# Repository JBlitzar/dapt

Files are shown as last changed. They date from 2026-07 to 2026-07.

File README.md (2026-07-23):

# dapt

## [Please read] About cost.

So looking at the bom, you can see that it's super expensive, like $50. You might be thinking, "what's going on there? I thought this project was explicitly focused on being low-cost!"

There are a few points I'd like to preempt.

1. I'm not going to spend $50 building this, and if I do so it'll be fine because I can pay out of pocket. That's the BOM for the souped-up set of ALL the adapters in large quantities. I'm going to pick and choose which ones to do, and do it in small quantities. I'm going to end up paying like $15 personally. 
2. There's not really a way to BOM-optimize. Contention genuinely is really high, because LCSC doesn't specialize in THT hobby-solderable components. USB-C SMD genuinely cannot be hand-soldered without a hot plate. If you're trying to make 100 of these, please just buy PCBA and get dirt-cheap SMD components. Right now THT pricing is hit-or-miss. Some are dirt cheap, others are not. 
3. I *could* swap everything out for SMD and order PCBA myself, but at that point it's genuinely a different project. This is what there is. 

## Images

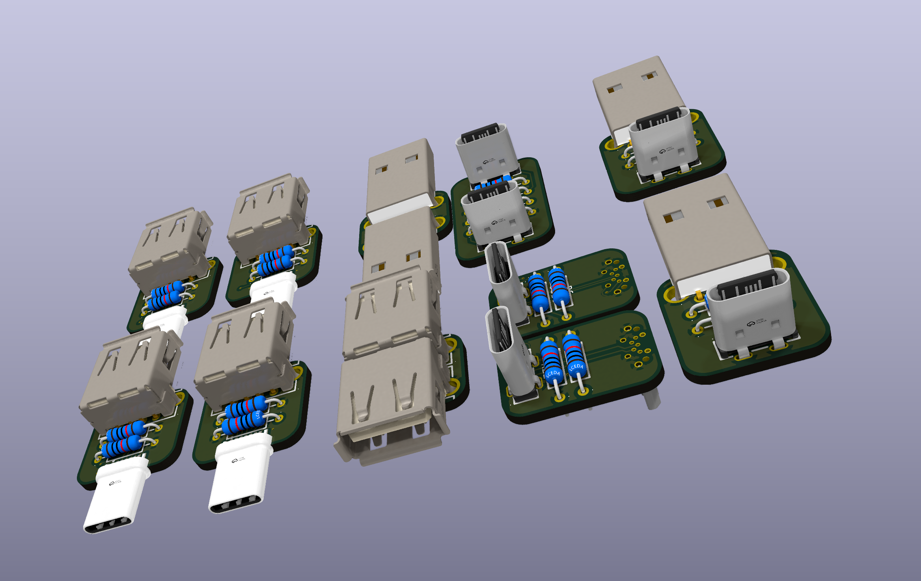
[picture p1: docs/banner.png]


There are no other enclosures, so this is the 3D model too. A STEP export is at `dapt.step`

## What is this project?

dapt is a family of USB adapters. 

There are some opinionated choices that were made:

- Fully passive and chipless. This means that it's just the bare USB protocol: GND, VCC, D+, D-. This also means that you lose out on PD and USB3.0. It's out of scope, but it's what makes this so universal. The only component other than the connectors are some 5.1k resistors that are required for all USB-C to work. 
- tht (for now). This is so that it's hand-solderable.
- just USB. It doesn't try to do too much.

I made dapt because I wanted some dead-simple USB adapters, and I thought it'd be a fun project.

Current adapters:
- A female to A female
- A female to C male
- A male to A male
- A male to C female
- C female to C female
- C female to micro male

## Schematics

| Variant | Schematic |
|---|---|
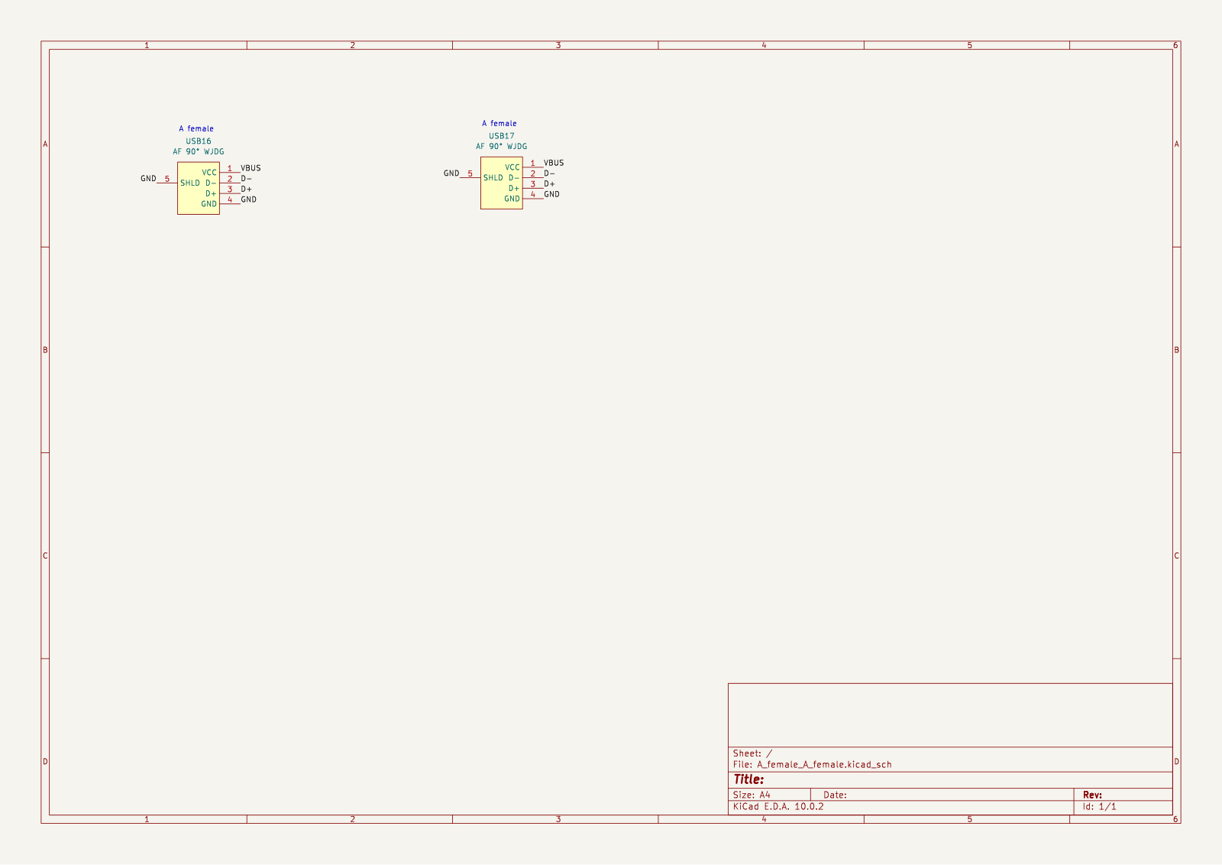
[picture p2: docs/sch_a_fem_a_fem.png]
A female to A female schematic
| A female to A female |  |
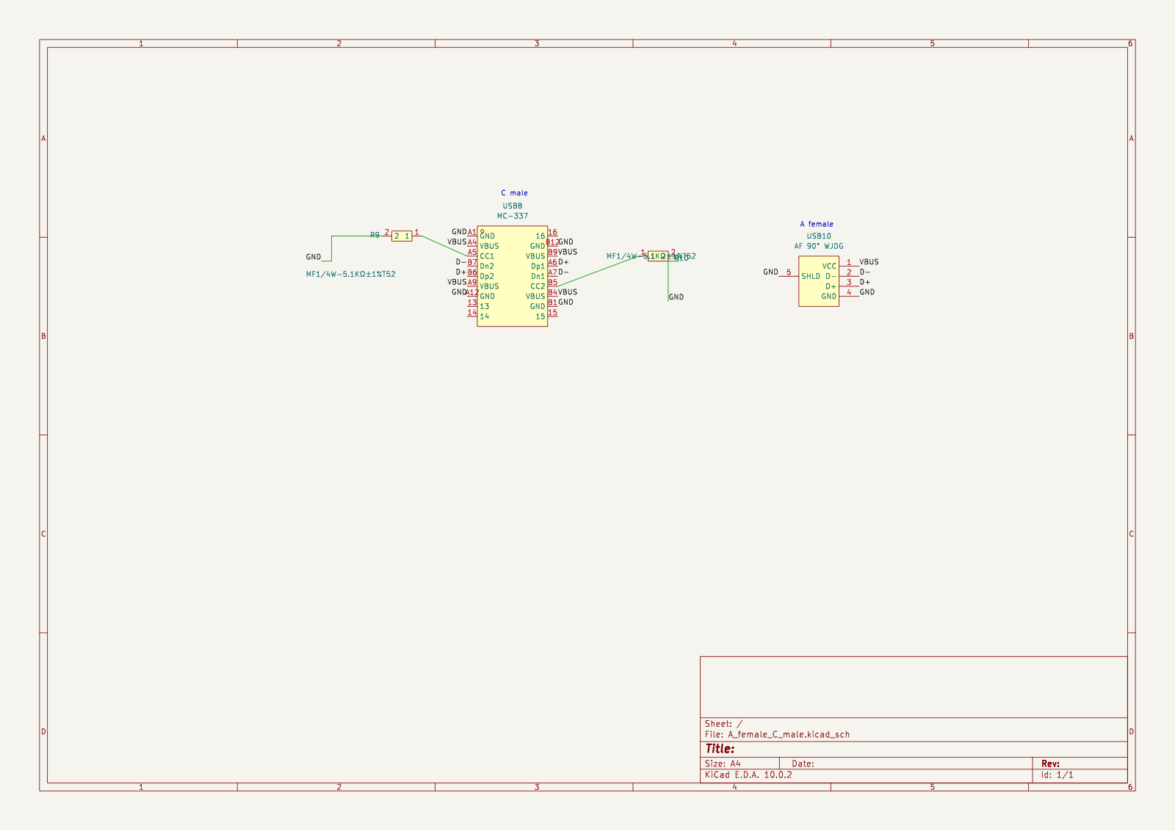
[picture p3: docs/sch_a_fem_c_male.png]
A female to C male schematic
| A female to C male |  |
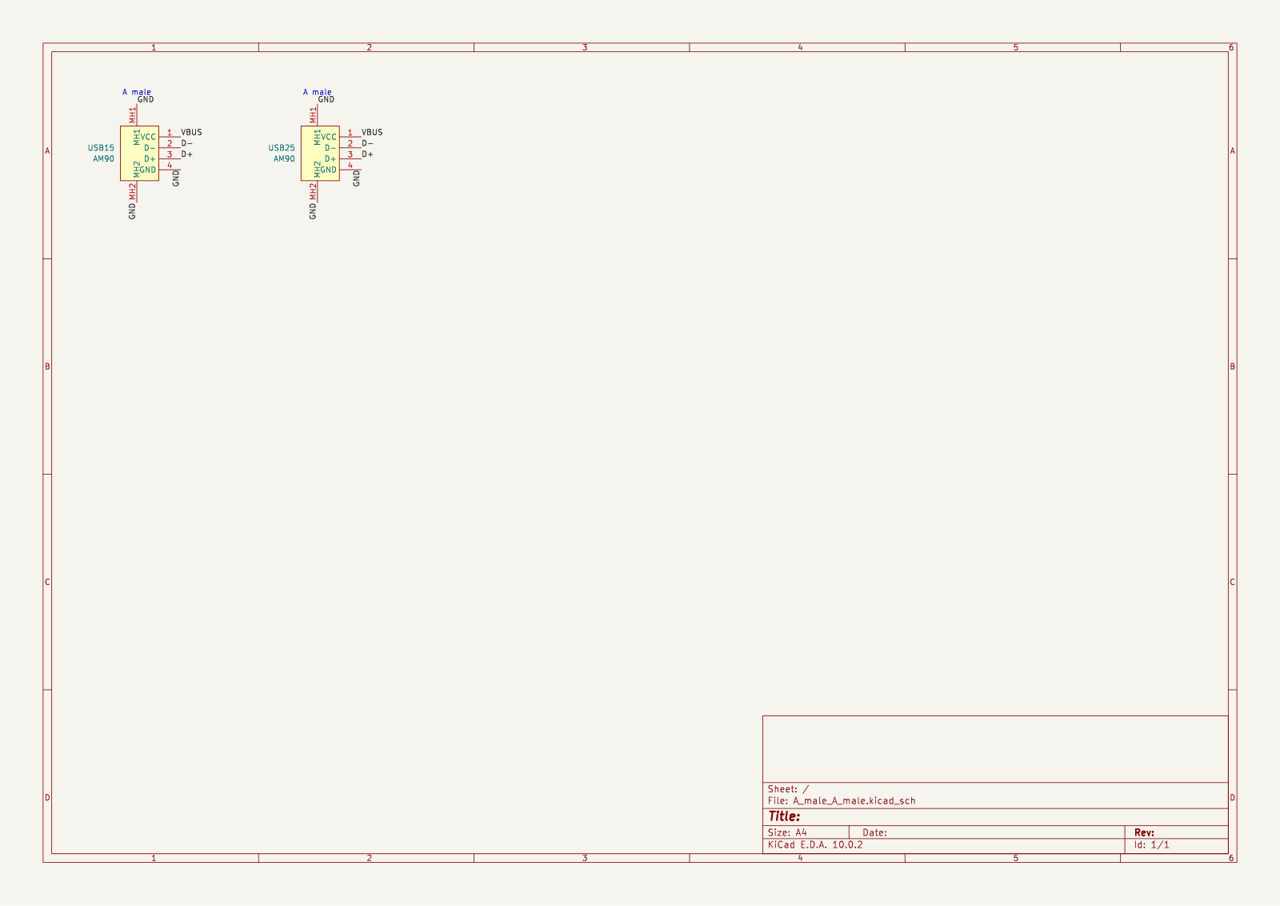
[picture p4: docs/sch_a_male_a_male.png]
A male to A male schematic
| A male to A male |  |
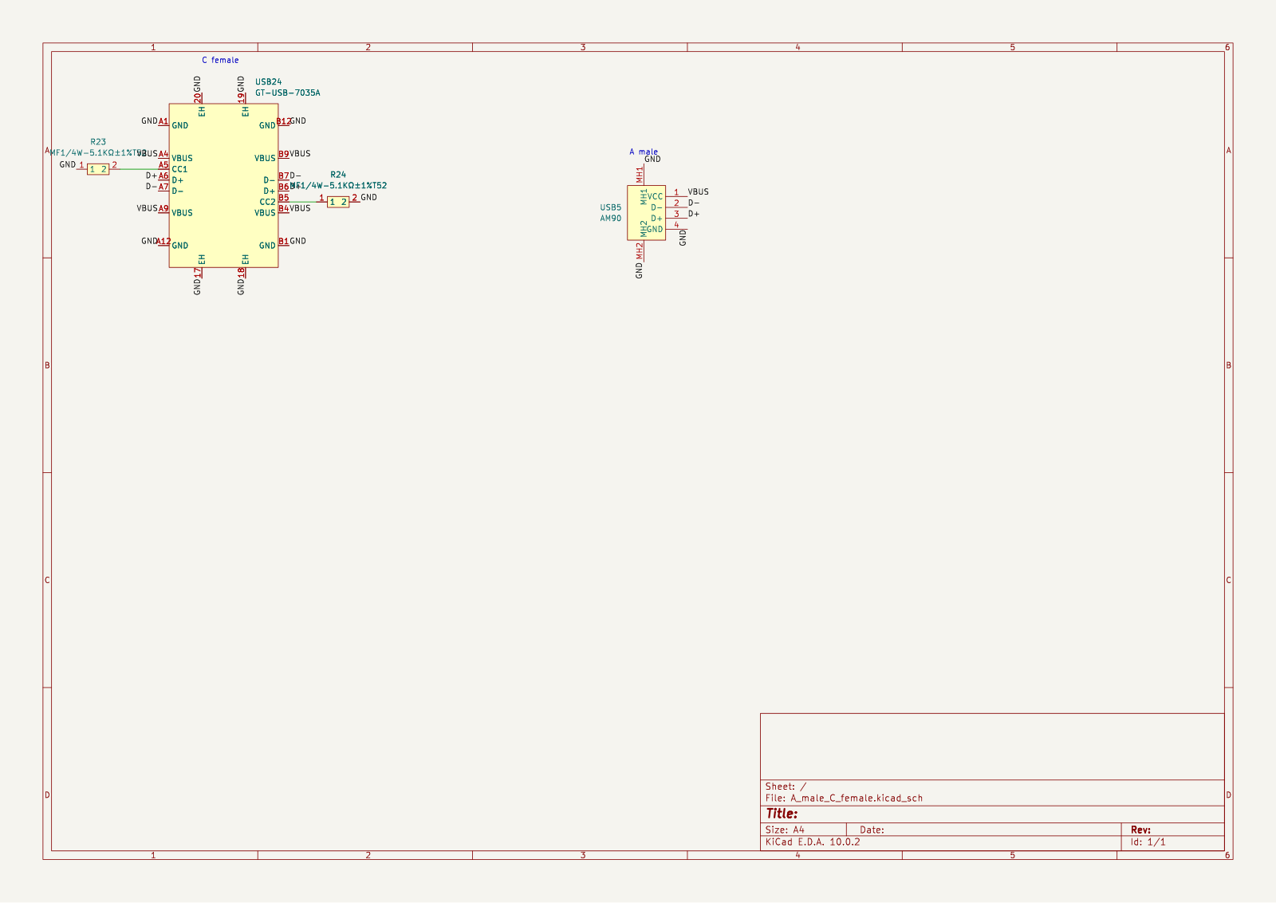
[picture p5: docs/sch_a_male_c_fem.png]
A male to C female schematic
| A male to C female |  |
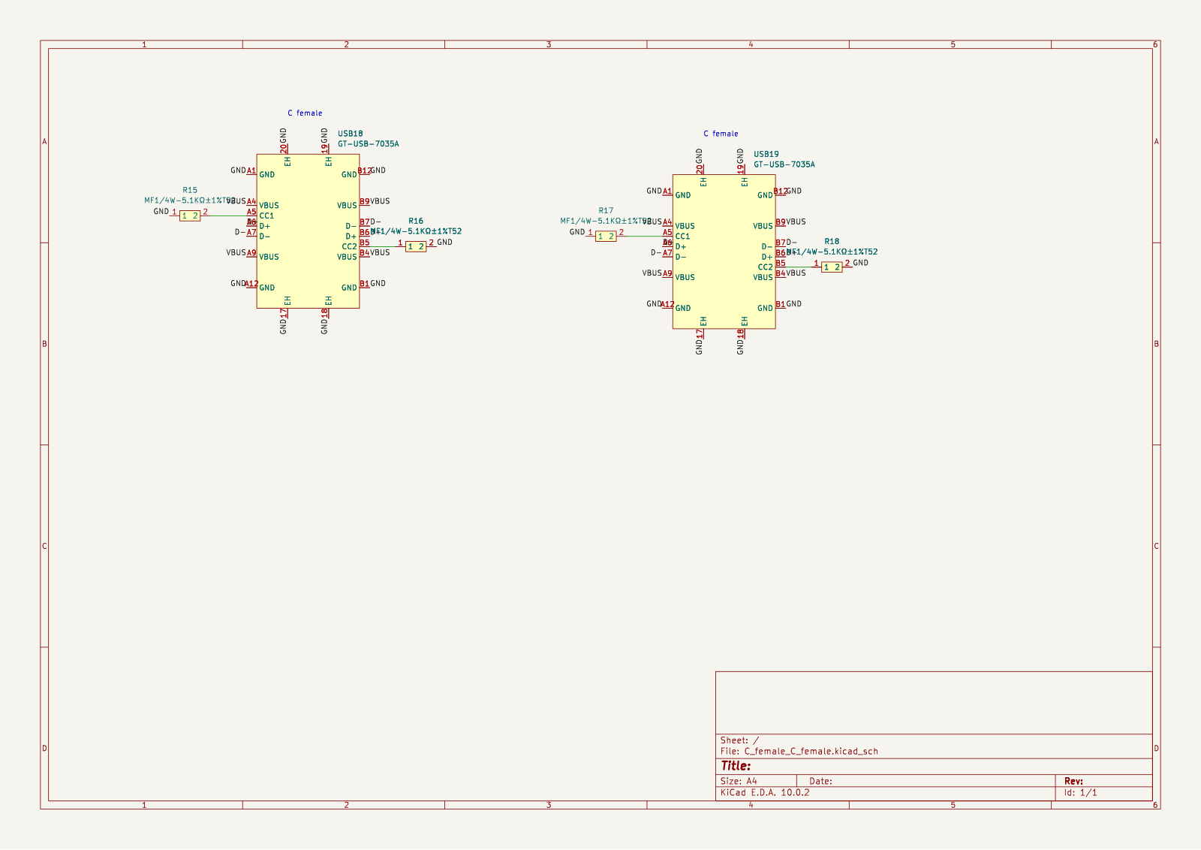
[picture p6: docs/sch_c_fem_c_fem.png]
C female to C female schematic
| C female to C female |  |
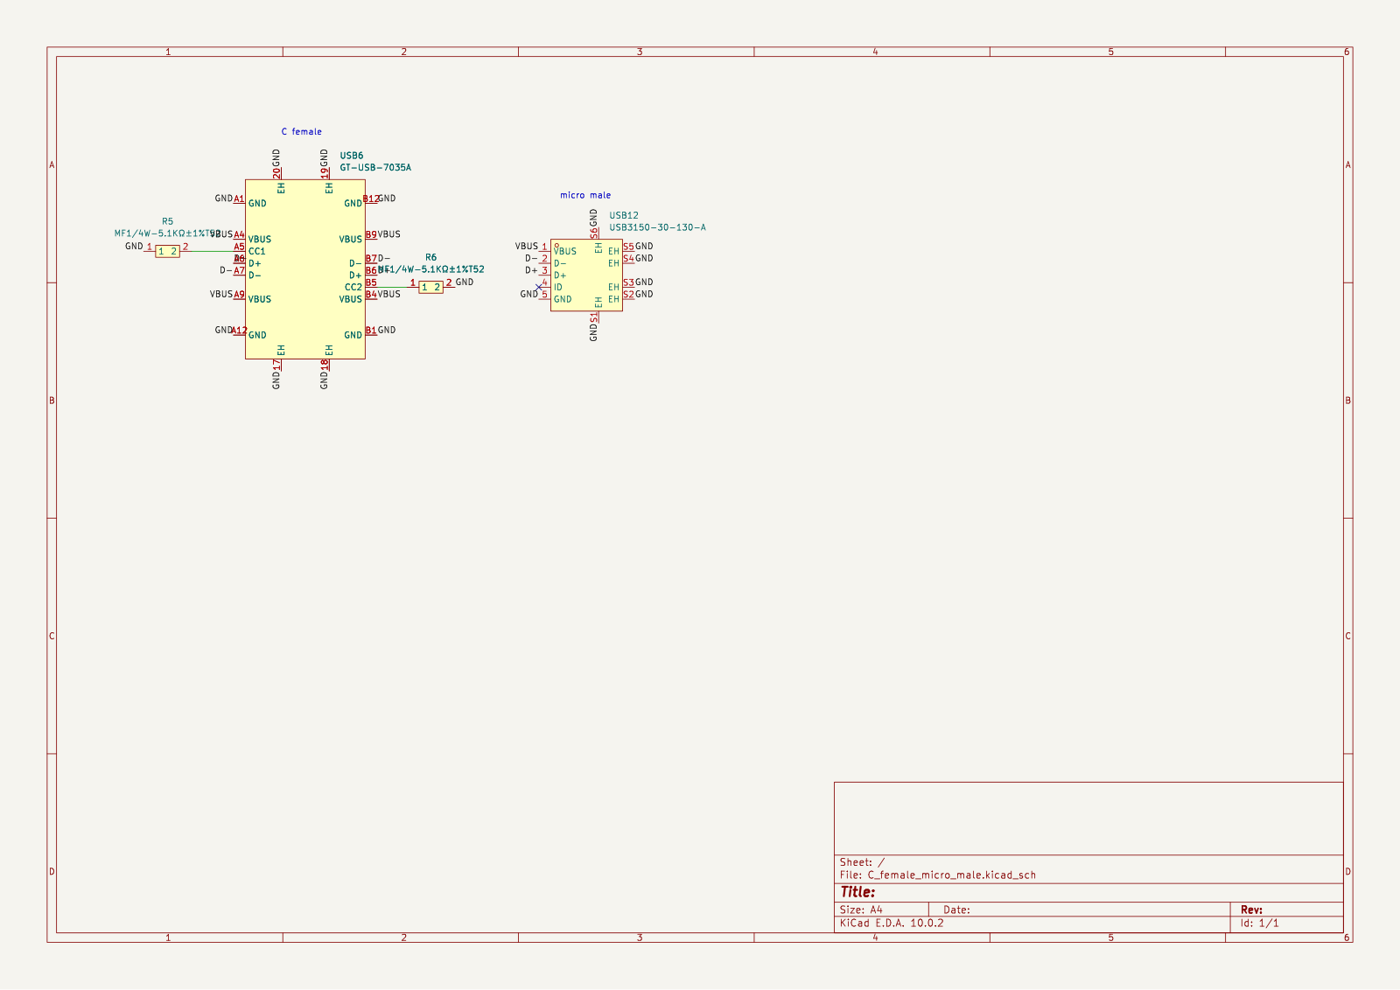
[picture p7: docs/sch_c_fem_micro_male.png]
C female to micro male schematic
| C female to micro male |  |

## PCB

| Variant | Front | Back |
|---|---|---|
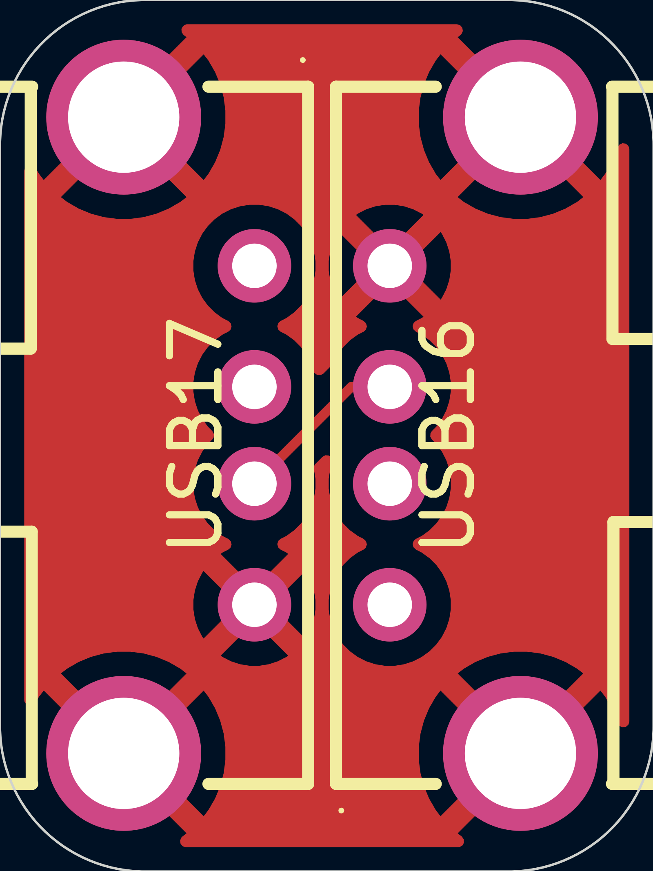
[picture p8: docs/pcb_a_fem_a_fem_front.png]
A female to A female PCB front
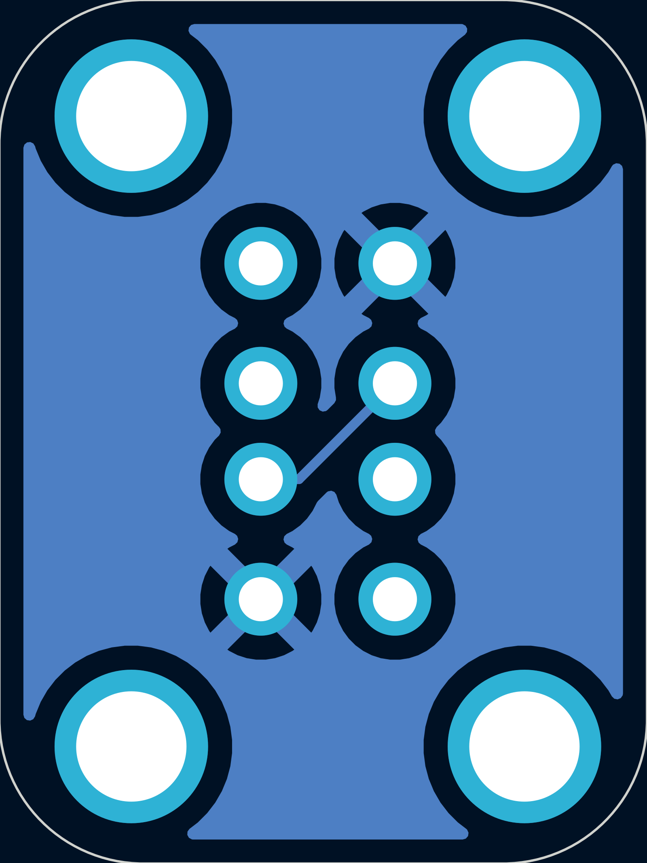
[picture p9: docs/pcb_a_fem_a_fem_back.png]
A female to A female PCB back
| A female to A female |  |  |
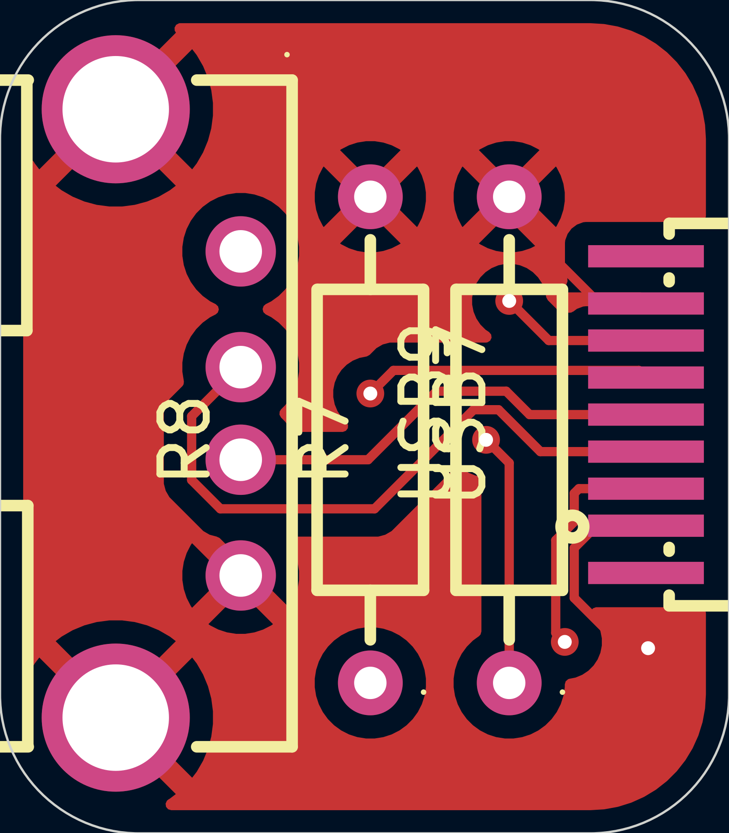
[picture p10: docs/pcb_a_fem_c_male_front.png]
A female to C male PCB front
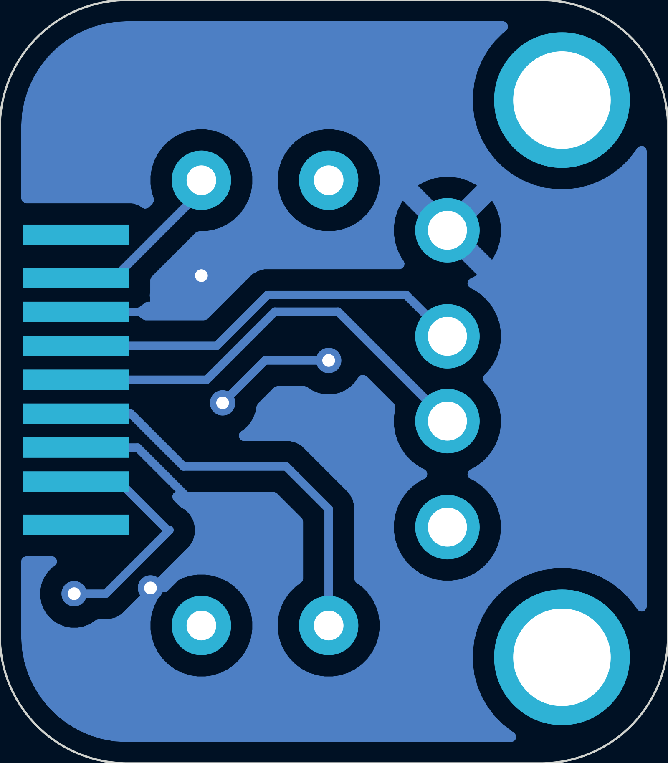
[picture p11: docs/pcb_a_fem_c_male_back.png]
A female to C male PCB back
| A female to C male |  |  |
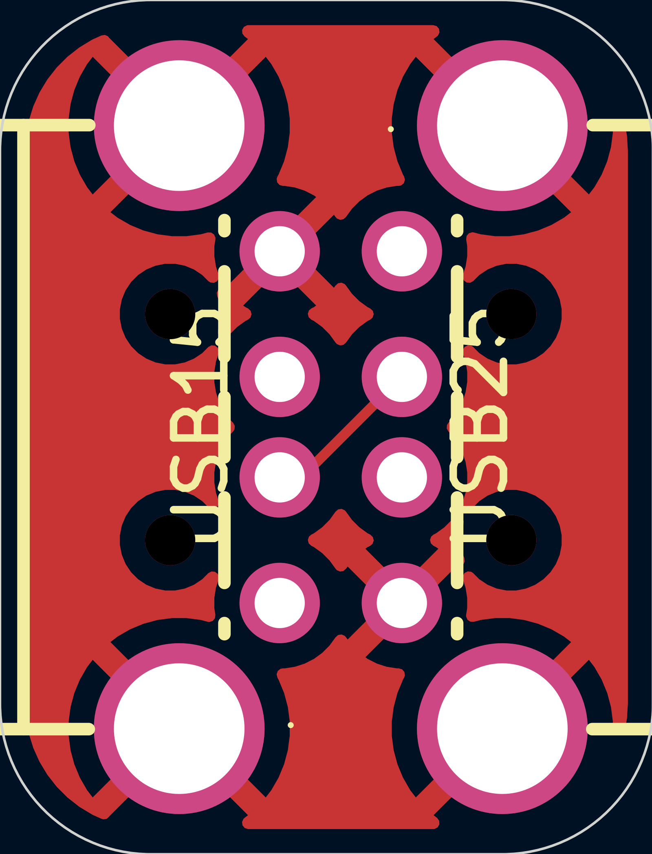
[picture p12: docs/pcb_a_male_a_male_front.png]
A male to A male PCB front
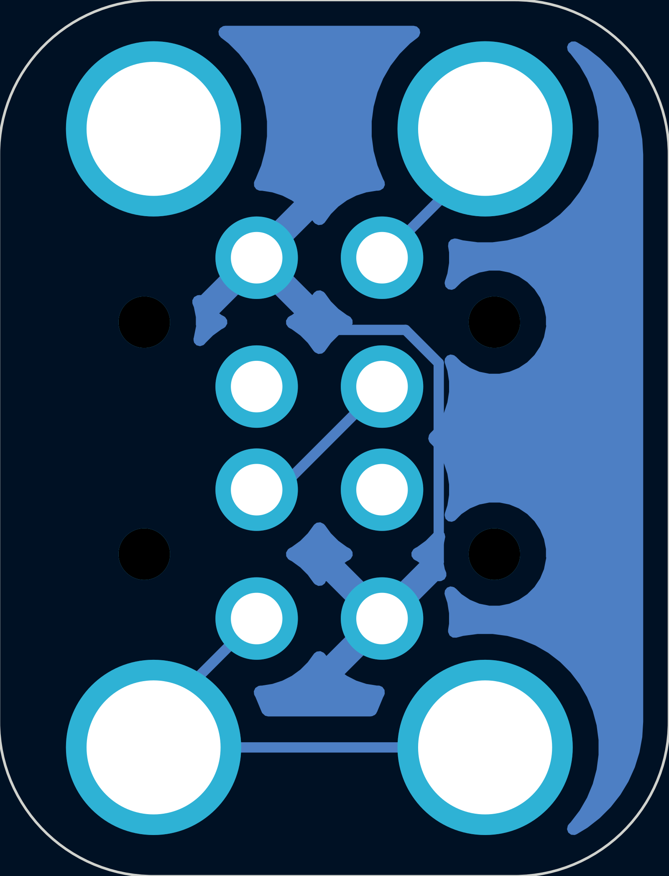
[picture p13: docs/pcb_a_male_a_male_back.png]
A male to A male PCB back
| A male to A male |  |  |
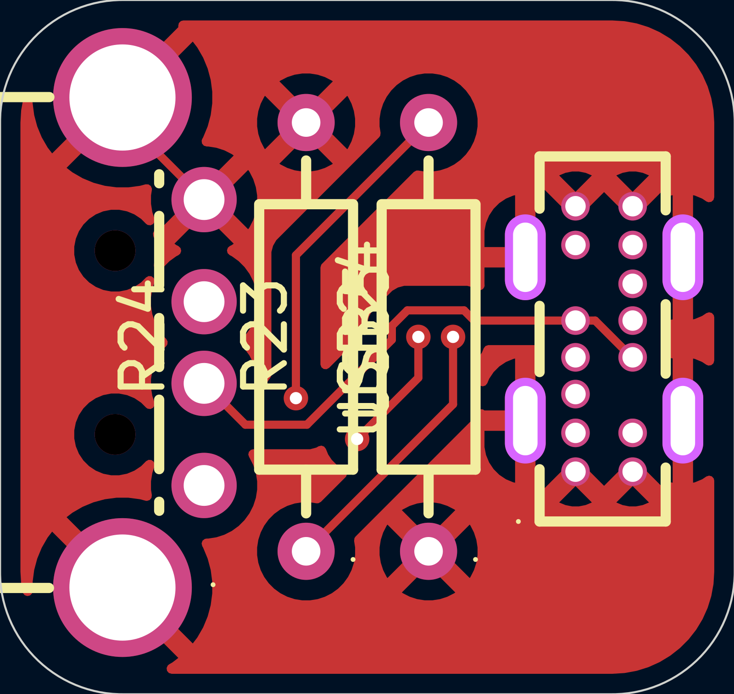
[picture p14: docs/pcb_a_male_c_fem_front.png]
A male to C female PCB front
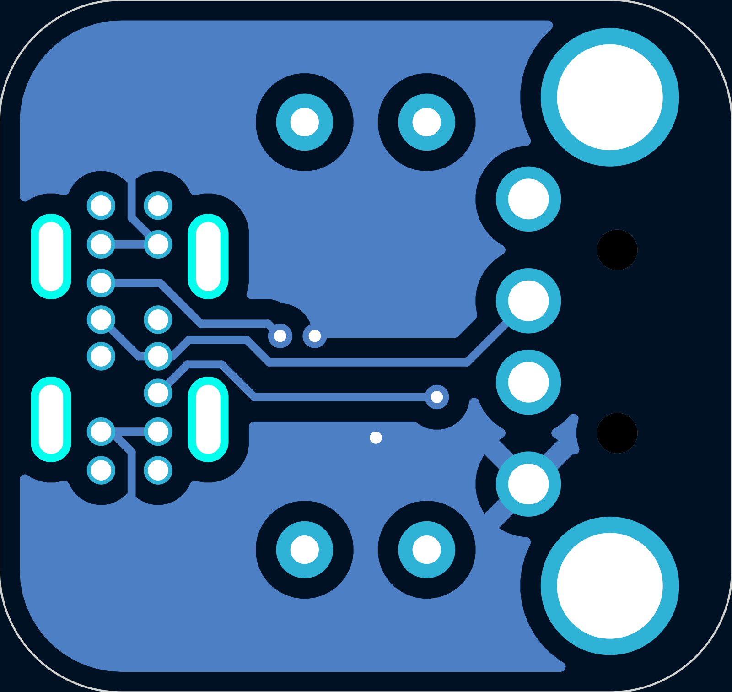
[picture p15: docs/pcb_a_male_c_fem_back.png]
A male to C female PCB back
| A male to C female |  |  |
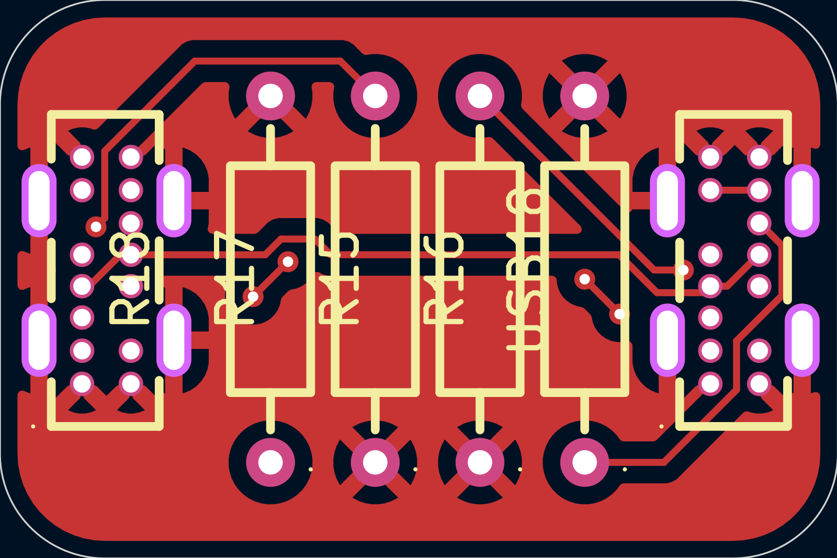
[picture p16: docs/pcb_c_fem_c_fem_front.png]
C female to C female PCB front
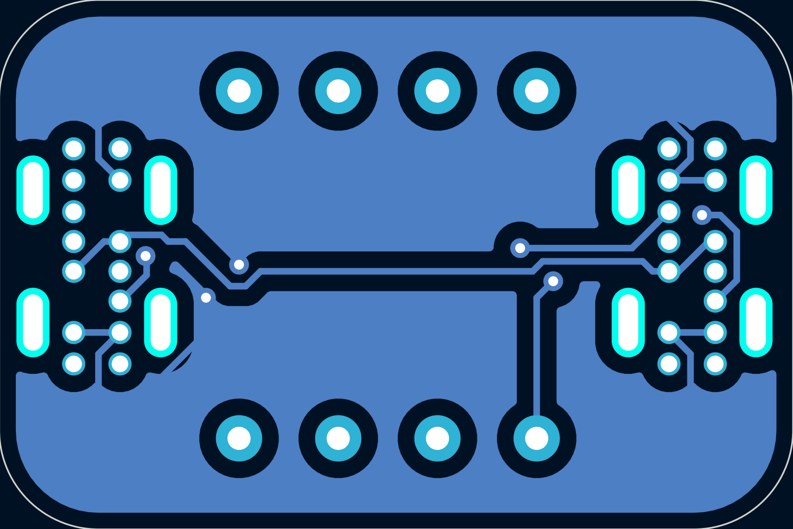
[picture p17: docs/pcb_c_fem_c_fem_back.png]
C female to C female PCB back
| C female to C female |  |  |
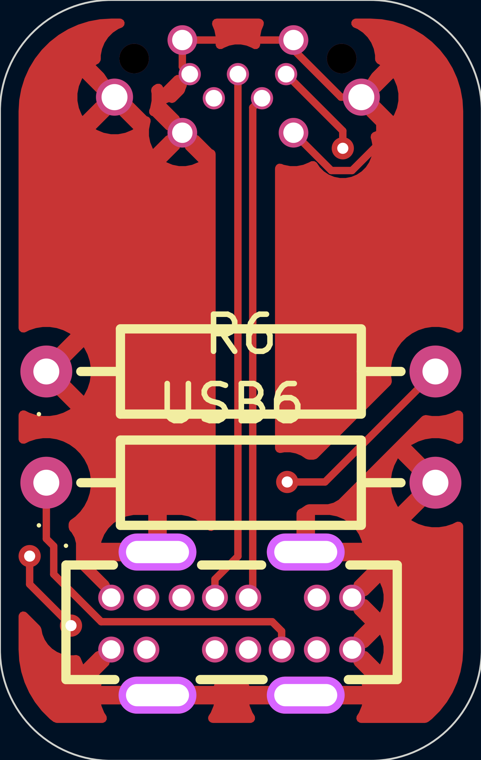
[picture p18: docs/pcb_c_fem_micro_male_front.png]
C female to micro male PCB front
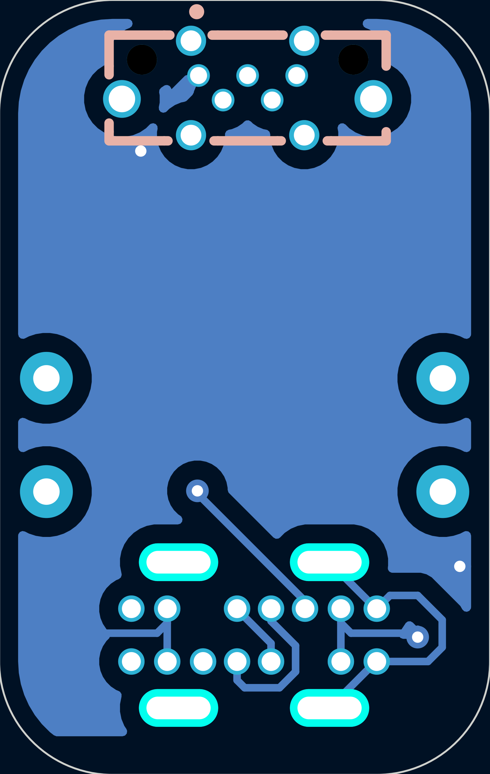
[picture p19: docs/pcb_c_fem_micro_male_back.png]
C female to micro male PCB back
| C female to micro male |  |  |

## Production files

in [`PCB/exported_variants/gerbers`](PCB/exported_variants/gerbers). A bit unique because this is multiple boards/variants in one.

## BOM

Please see the *about cost* section.

|Item |link |qty|extended price|notes |
|---|---|---|---|---|
|C male A female board |N/A |20 |5.1 | |
|A male A male board |N/A |5  |4.2 | |
|C female C female board  |N/A |5  |2.1 | |
|A male C female board |N/A |10 |5.2 | |
|C female micro male board|N/A |10 |5.5 | |
|USB A male |https://www.lcsc.com/product-detail/C404965.html?s_z=n_q_C404965&globalKeyword=C404965 |15 |1.33 | |
|USB A female |https://www.lcsc.com/product-detail/C456018.html?s_z=n_q_C456018&globalKeyword=C456018 |20 |0.97 | |
|USB C male |https://www.lcsc.com/product-detail/C22355747.html?s_z=n_q_C22355747&globalKeyword=C22355747|20 |5.85 | |
|USB C female |https://www.lcsc.com/product-detail/C22384780.html?s_z=n_q_C22384780&globalKeyword=C22384780|30 |8.53 | |
|micro male |https://www.lcsc.com/product-detail/C7407276.html?s_z=n_q_C7407276&globalKeyword=C7407276 |10 |11.75 | |
|lcsc + jlc shipping |N/A |1  |0 |shipping free bc imma order it with other stuff|
|total |N/A |1  |50.53 | |

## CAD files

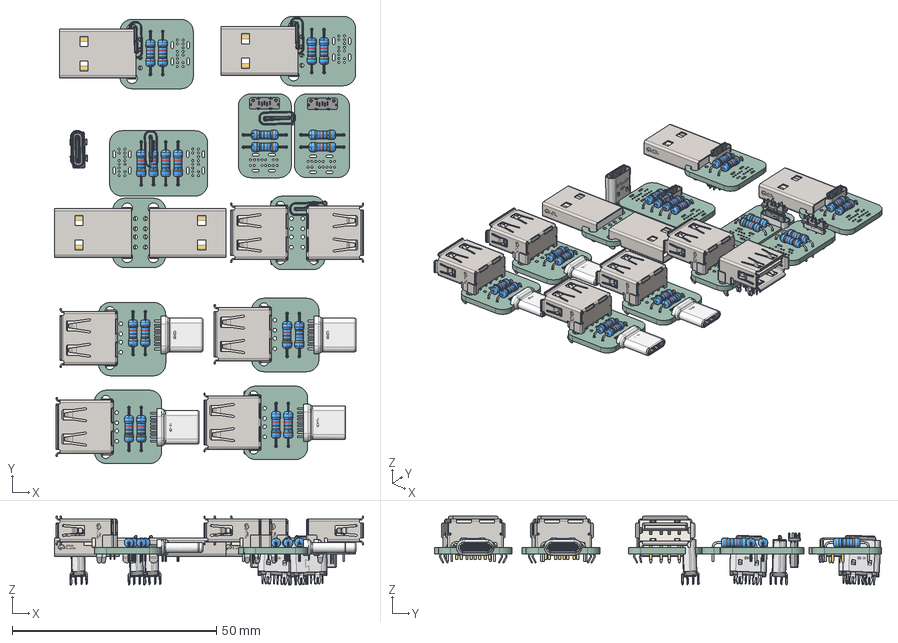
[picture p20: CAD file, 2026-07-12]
docs/dapt.step
75.6 x 109.5 x 16.8 mm
USB-AM-TH_AM90 x 4
RES-TH_D2.3-L6.5-P10.50 x 20
TYPE-C-TH_GT-USB-7035A x 6
USB-A-TH_4P-L14.5-W14.0-H7.6-S2.71 x 6
USB-C-SMD_UCR1-7X3X66068 x 4
USB-B-TH_USB3150-30-130-A x 2
dapt_PCB_1
dapt_PCB_2
dapt_PCB_3
dapt_PCB_4
dapt_PCB_5
dapt_PCB_6
dapt_PCB_7
dapt_PCB_8
dapt_PCB_9
dapt_PCB_10
dapt_PCB_11

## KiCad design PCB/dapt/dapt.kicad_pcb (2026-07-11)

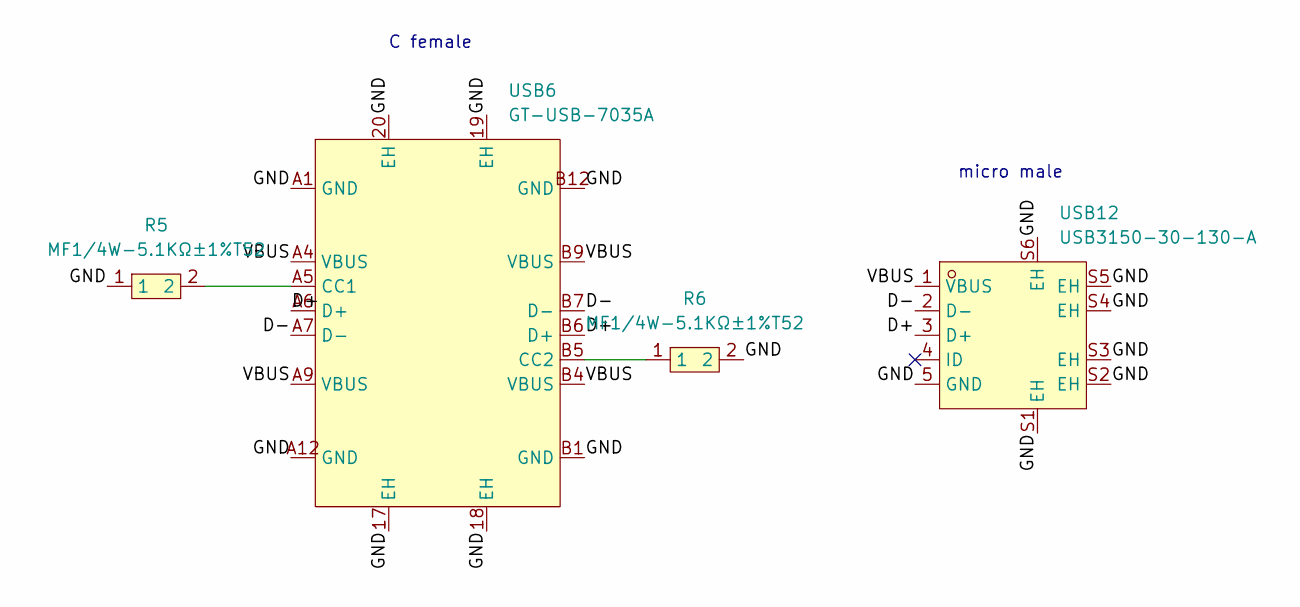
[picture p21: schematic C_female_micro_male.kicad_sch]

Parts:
R5, R6: MF1/4W-5.1KΩ±1%T52; RES-TH_BD2.3-L6.5-P10.50-D0.5; MPN MF1/4W-5.1KΩ±1%T52; LCSC Part C714010
USB6: GT-USB-7035A; TYPE-C-TH_GT-USB-7035A; MPN GT-USB-7035A; LCSC Part C22384780
USB12: USB3150-30-130-A; USB-B-TH_USB3150-30-130-A; MPN USB3150-30-130-A; LCSC Part C7407276

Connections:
/C_female_micro_male/D+: USB6.A6 (D+), USB6.B6 (D+), USB12.3 (D+)
/C_female_micro_male/D-: USB6.A7 (D-), USB6.B7 (D-), USB12.2 (D-)
/C_female_micro_male/GND: R5.1, R6.2, USB6.17 (EH), USB6.18 (EH), USB6.19 (EH), USB6.20 (EH), USB6.A1 (GND), USB6.A12 (GND), USB6.B1 (GND), USB6.B12 (GND), USB12.5 (GND), USB12.S1 (EH), USB12.S2 (EH), USB12.S3 (EH), USB12.S4 (EH), USB12.S5 (EH), USB12.S6 (EH)
/C_female_micro_male/VBUS: USB6.A4 (VBUS), USB6.A9 (VBUS), USB6.B4 (VBUS), USB6.B9 (VBUS), USB12.1 (VBUS)
unnamed: R5.2, USB6.A5 (CC1)
unnamed: R6.1, USB6.B5 (CC2)

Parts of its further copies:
R21, R22: MF1/4W-5.1KΩ±1%T52; RES-TH_BD2.3-L6.5-P10.50-D0.5; MPN MF1/4W-5.1KΩ±1%T52; LCSC Part C714010
USB22: GT-USB-7035A; TYPE-C-TH_GT-USB-7035A; MPN GT-USB-7035A; LCSC Part C22384780
USB23: USB3150-30-130-A; USB-B-TH_USB3150-30-130-A; MPN USB3150-30-130-A; LCSC Part C7407276

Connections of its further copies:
/C_female_micro_male1/D+: USB22.A6 (D+), USB22.B6 (D+), USB23.3 (D+)
/C_female_micro_male1/D-: USB22.A7 (D-), USB22.B7 (D-), USB23.2 (D-)
/C_female_micro_male1/GND: R21.1, R22.2, USB22.17 (EH), USB22.18 (EH), USB22.19 (EH), USB22.20 (EH), USB22.A1 (GND), USB22.A12 (GND), USB22.B1 (GND), USB22.B12 (GND), USB23.5 (GND), USB23.S1 (EH), USB23.S2 (EH), USB23.S3 (EH), USB23.S4 (EH), USB23.S5 (EH), USB23.S6 (EH)
/C_female_micro_male1/VBUS: USB22.A4 (VBUS), USB22.A9 (VBUS), USB22.B4 (VBUS), USB22.B9 (VBUS), USB23.1 (VBUS)
unnamed: R21.2, USB22.A5 (CC1)
unnamed: R22.1, USB22.B5 (CC2)

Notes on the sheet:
C female
micro male

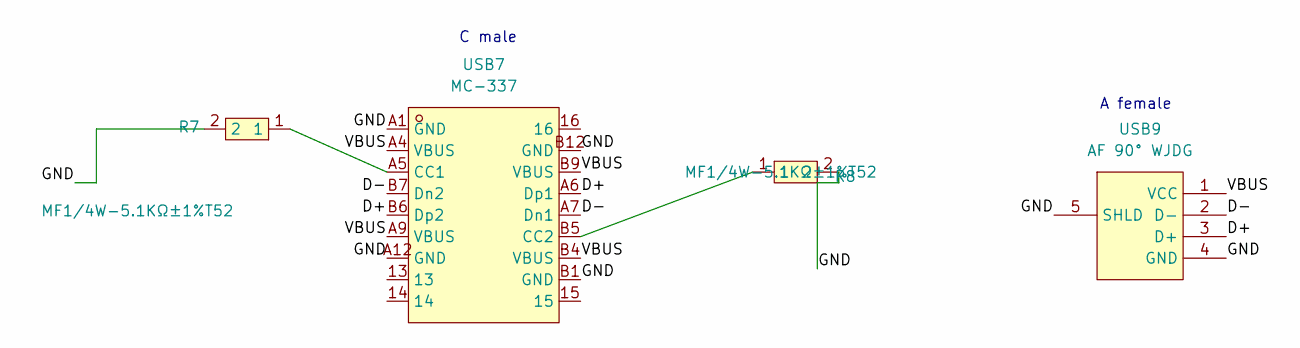
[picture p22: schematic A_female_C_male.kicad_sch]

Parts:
R7, R8: MF1/4W-5.1KΩ±1%T52; RES-TH_BD2.3-L6.5-P10.50-D0.5; MPN MF1/4W-5.1KΩ±1%T52; LCSC Part C714010
USB7: MC-337; USB-C-SMD_14P-P0.80_MC-337; MPN MC-337; LCSC Part C22355747
USB9: AF 90° WJDG; USB-A-TH_AF-WJDG; MPN AF 90° WJDG; LCSC Part C456018

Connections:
/A_female_C_male/D+: USB7.A6 (Dp1), USB7.B6 (Dp2), USB9.3 (D+)
/A_female_C_male/D-: USB7.A7 (Dn1), USB7.B7 (Dn2), USB9.2 (D-)
/A_female_C_male/GND: R7.2, R8.2, USB7.A1 (GND), USB7.A12 (GND), USB7.B1 (GND), USB7.B12 (GND), USB9.4 (GND), USB9.5 (SHLD)
/A_female_C_male/VBUS: USB7.A4 (VBUS), USB7.A9 (VBUS), USB7.B4 (VBUS), USB7.B9 (VBUS), USB9.1 (VCC)
unnamed: R7.1, USB7.A5 (CC1)
unnamed: R8.1, USB7.B5 (CC2)

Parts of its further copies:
R9, R10, R11, R12, R19, R20: MF1/4W-5.1KΩ±1%T52; RES-TH_BD2.3-L6.5-P10.50-D0.5; MPN MF1/4W-5.1KΩ±1%T52; LCSC Part C714010
USB8, USB11, USB20: MC-337; USB-C-SMD_14P-P0.80_MC-337; MPN MC-337; LCSC Part C22355747
USB10, USB13, USB21: AF 90° WJDG; USB-A-TH_AF-WJDG; MPN AF 90° WJDG; LCSC Part C456018

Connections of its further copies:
/A_female_C_male1/D+: USB8.A6 (Dp1), USB8.B6 (Dp2), USB10.3 (D+)
/A_female_C_male1/D-: USB8.A7 (Dn1), USB8.B7 (Dn2), USB10.2 (D-)
/A_female_C_male1/GND: R9.2, R10.2, USB8.A1 (GND), USB8.A12 (GND), USB8.B1 (GND), USB8.B12 (GND), USB10.4 (GND), USB10.5 (SHLD)
/A_female_C_male1/VBUS: USB8.A4 (VBUS), USB8.A9 (VBUS), USB8.B4 (VBUS), USB8.B9 (VBUS), USB10.1 (VCC)
/A_female_C_male2/D+: USB11.A6 (Dp1), USB11.B6 (Dp2), USB13.3 (D+)
/A_female_C_male2/D-: USB11.A7 (Dn1), USB11.B7 (Dn2), USB13.2 (D-)
/A_female_C_male2/GND: R11.2, R12.2, USB11.A1 (GND), USB11.A12 (GND), USB11.B1 (GND), USB11.B12 (GND), USB13.4 (GND), USB13.5 (SHLD)
/A_female_C_male2/VBUS: USB11.A4 (VBUS), USB11.A9 (VBUS), USB11.B4 (VBUS), USB11.B9 (VBUS), USB13.1 (VCC)
/A_female_C_male3/D+: USB20.A6 (Dp1), USB20.B6 (Dp2), USB21.3 (D+)
/A_female_C_male3/D-: USB20.A7 (Dn1), USB20.B7 (Dn2), USB21.2 (D-)
/A_female_C_male3/GND: R19.2, R20.2, USB20.A1 (GND), USB20.A12 (GND), USB20.B1 (GND), USB20.B12 (GND), USB21.4 (GND), USB21.5 (SHLD)
/A_female_C_male3/VBUS: USB20.A4 (VBUS), USB20.A9 (VBUS), USB20.B4 (VBUS), USB20.B9 (VBUS), USB21.1 (VCC)
unnamed: R9.1, USB8.A5 (CC1)
unnamed: R10.1, USB8.B5 (CC2)
unnamed: R11.1, USB11.A5 (CC1)
unnamed: R12.1, USB11.B5 (CC2)
unnamed: R19.1, USB20.A5 (CC1)
unnamed: R20.1, USB20.B5 (CC2)

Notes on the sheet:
C male
A female

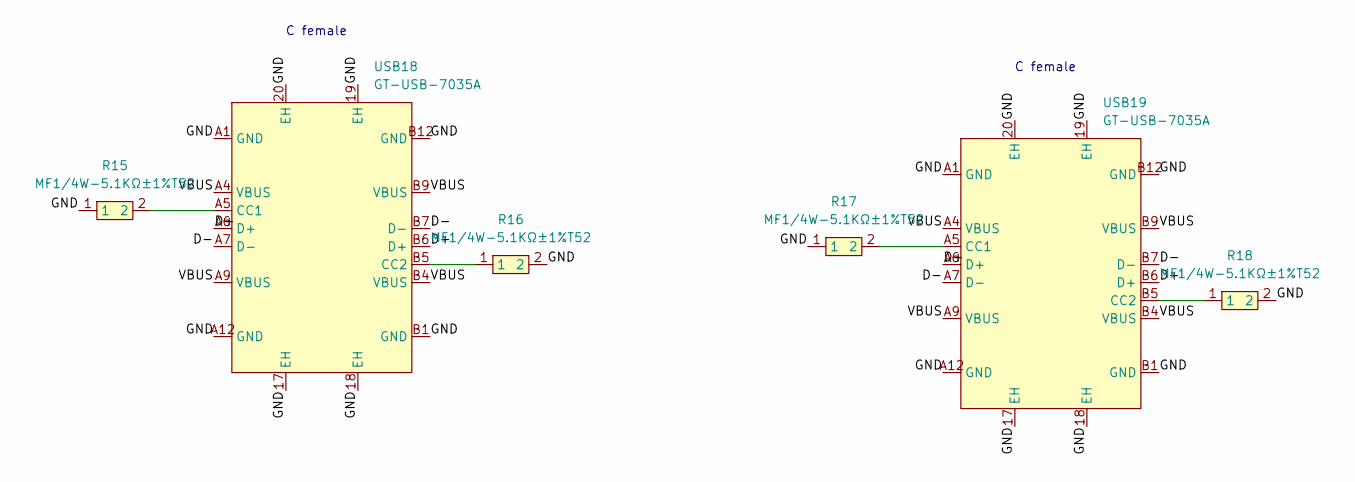
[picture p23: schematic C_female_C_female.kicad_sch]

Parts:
R15, R16, R17, R18: MF1/4W-5.1KΩ±1%T52; RES-TH_BD2.3-L6.5-P10.50-D0.5; MPN MF1/4W-5.1KΩ±1%T52; LCSC Part C714010
USB18, USB19: GT-USB-7035A; TYPE-C-TH_GT-USB-7035A; MPN GT-USB-7035A; LCSC Part C22384780

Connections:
/C_female_C_female/D+: USB18.A6 (D+), USB18.B6 (D+), USB19.A6 (D+), USB19.B6 (D+)
/C_female_C_female/D-: USB18.A7 (D-), USB18.B7 (D-), USB19.A7 (D-), USB19.B7 (D-)
/C_female_C_female/GND: R15.1, R16.2, R17.1, R18.2, USB18.17 (EH), USB18.18 (EH), USB18.19 (EH), USB18.20 (EH), USB18.A1 (GND), USB18.A12 (GND), USB18.B1 (GND), USB18.B12 (GND), USB19.17 (EH), USB19.18 (EH), USB19.19 (EH), USB19.20 (EH), USB19.A1 (GND), USB19.A12 (GND), USB19.B1 (GND), USB19.B12 (GND)
/C_female_C_female/VBUS: USB18.A4 (VBUS), USB18.A9 (VBUS), USB18.B4 (VBUS), USB18.B9 (VBUS), USB19.A4 (VBUS), USB19.A9 (VBUS), USB19.B4 (VBUS), USB19.B9 (VBUS)
unnamed: R15.2, USB18.A5 (CC1)
unnamed: R16.1, USB18.B5 (CC2)
unnamed: R17.2, USB19.A5 (CC1)
unnamed: R18.1, USB19.B5 (CC2)

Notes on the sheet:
C female

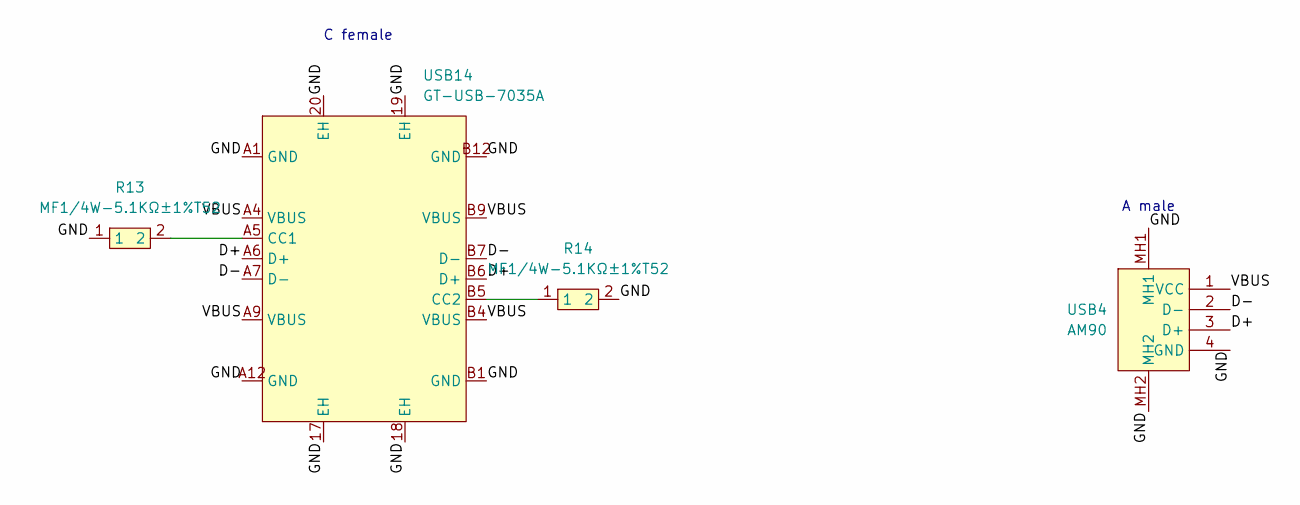
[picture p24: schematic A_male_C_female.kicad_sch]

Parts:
R13, R14: MF1/4W-5.1KΩ±1%T52; RES-TH_BD2.3-L6.5-P10.50-D0.5; MPN MF1/4W-5.1KΩ±1%T52; LCSC Part C714010
USB4: AM90; USB-AM-TH_AM90; MPN AM90; LCSC Part C404965
USB14: GT-USB-7035A; TYPE-C-TH_GT-USB-7035A; MPN GT-USB-7035A; LCSC Part C22384780

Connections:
/A_male_C_female/D+: USB4.3 (D+), USB14.A6 (D+), USB14.B6 (D+)
/A_male_C_female/D-: USB4.2 (D-), USB14.A7 (D-), USB14.B7 (D-)
/A_male_C_female/GND: R13.1, R14.2, USB4.4 (GND), USB4.MH1, USB4.MH2, USB14.17 (EH), USB14.18 (EH), USB14.19 (EH), USB14.20 (EH), USB14.A1 (GND), USB14.A12 (GND), USB14.B1 (GND), USB14.B12 (GND)
/A_male_C_female/VBUS: USB4.1 (VCC), USB14.A4 (VBUS), USB14.A9 (VBUS), USB14.B4 (VBUS), USB14.B9 (VBUS)
unnamed: R13.2, USB14.A5 (CC1)
unnamed: R14.1, USB14.B5 (CC2)

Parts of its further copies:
R23, R24: MF1/4W-5.1KΩ±1%T52; RES-TH_BD2.3-L6.5-P10.50-D0.5; MPN MF1/4W-5.1KΩ±1%T52; LCSC Part C714010
USB5: AM90; USB-AM-TH_AM90; MPN AM90; LCSC Part C404965
USB24: GT-USB-7035A; TYPE-C-TH_GT-USB-7035A; MPN GT-USB-7035A; LCSC Part C22384780

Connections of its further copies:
/A_male_C_female1/D+: USB5.3 (D+), USB24.A6 (D+), USB24.B6 (D+)
/A_male_C_female1/D-: USB5.2 (D-), USB24.A7 (D-), USB24.B7 (D-)
/A_male_C_female1/GND: R23.1, R24.2, USB5.4 (GND), USB5.MH1, USB5.MH2, USB24.17 (EH), USB24.18 (EH), USB24.19 (EH), USB24.20 (EH), USB24.A1 (GND), USB24.A12 (GND), USB24.B1 (GND), USB24.B12 (GND)
/A_male_C_female1/VBUS: USB5.1 (VCC), USB24.A4 (VBUS), USB24.A9 (VBUS), USB24.B4 (VBUS), USB24.B9 (VBUS)
unnamed: R23.2, USB24.A5 (CC1)
unnamed: R24.1, USB24.B5 (CC2)

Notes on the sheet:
A male
C female

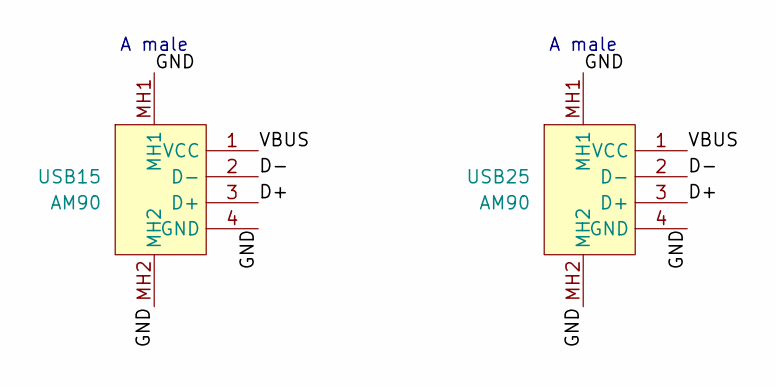
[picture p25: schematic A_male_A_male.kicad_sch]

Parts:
USB15, USB25: AM90; USB-AM-TH_AM90; MPN AM90; LCSC Part C404965

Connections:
/A_male_A_male/D+: USB15.3 (D+), USB25.3 (D+)
/A_male_A_male/D-: USB15.2 (D-), USB25.2 (D-)
/A_male_A_male/GND: USB15.4 (GND), USB15.MH1, USB15.MH2, USB25.4 (GND), USB25.MH1, USB25.MH2
/A_male_A_male/VBUS: USB15.1 (VCC), USB25.1 (VCC)

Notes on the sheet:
A male

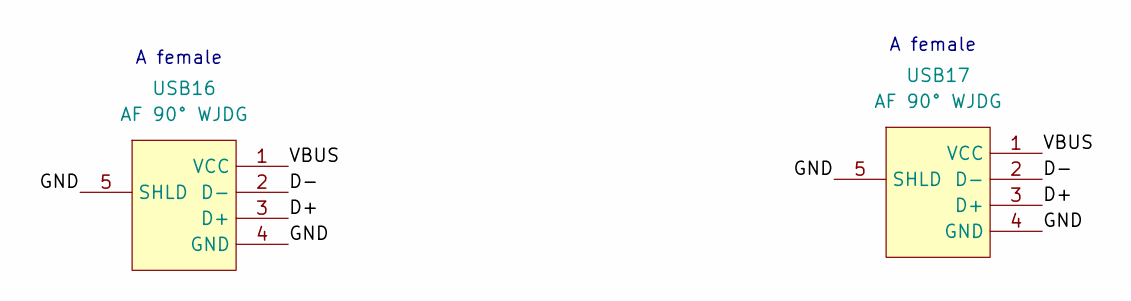
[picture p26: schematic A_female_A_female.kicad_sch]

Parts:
USB16, USB17: AF 90° WJDG; USB-A-TH_AF-WJDG; MPN AF 90° WJDG; LCSC Part C456018

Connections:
/A_female_A_female/D+: USB16.3 (D+), USB17.3 (D+)
/A_female_A_female/D-: USB16.2 (D-), USB17.2 (D-)
/A_female_A_female/GND: USB16.4 (GND), USB16.5 (SHLD), USB17.4 (GND), USB17.5 (SHLD)
/A_female_A_female/VBUS: USB16.1 (VCC), USB17.1 (VCC)

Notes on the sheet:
A female

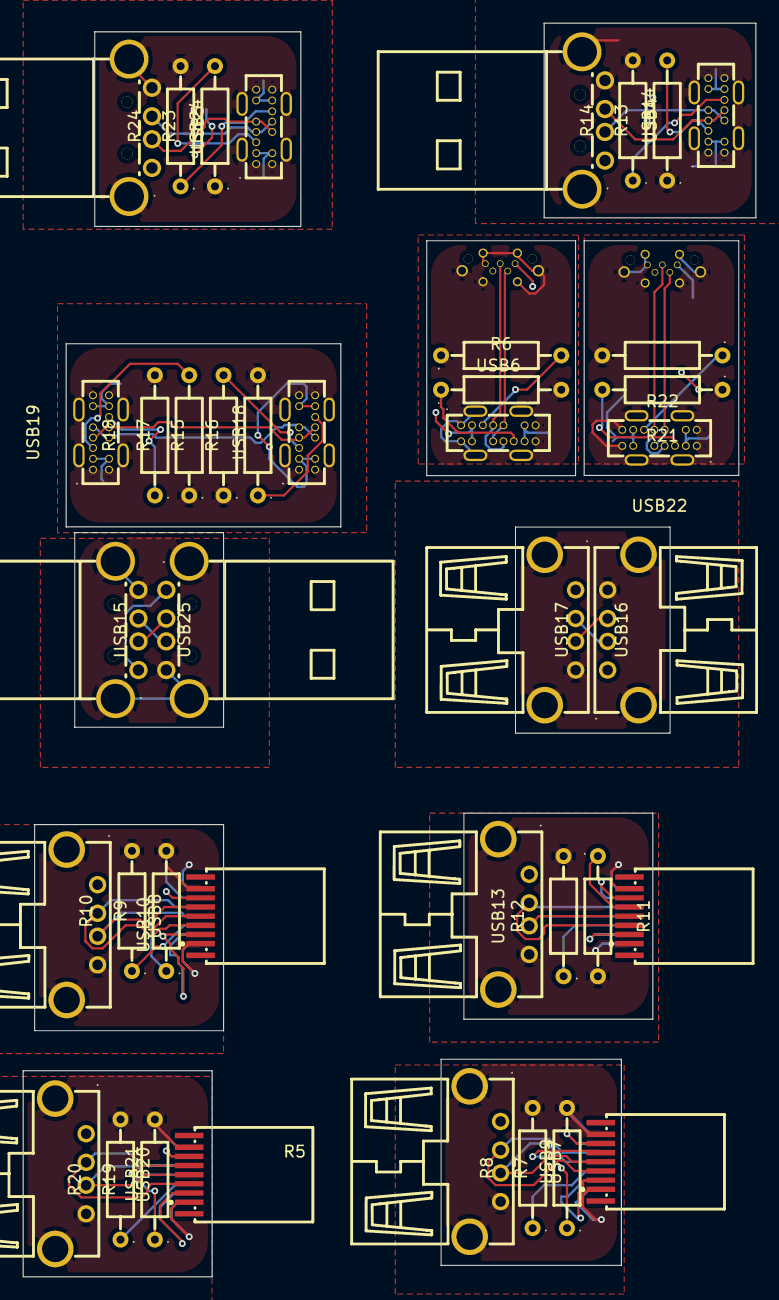
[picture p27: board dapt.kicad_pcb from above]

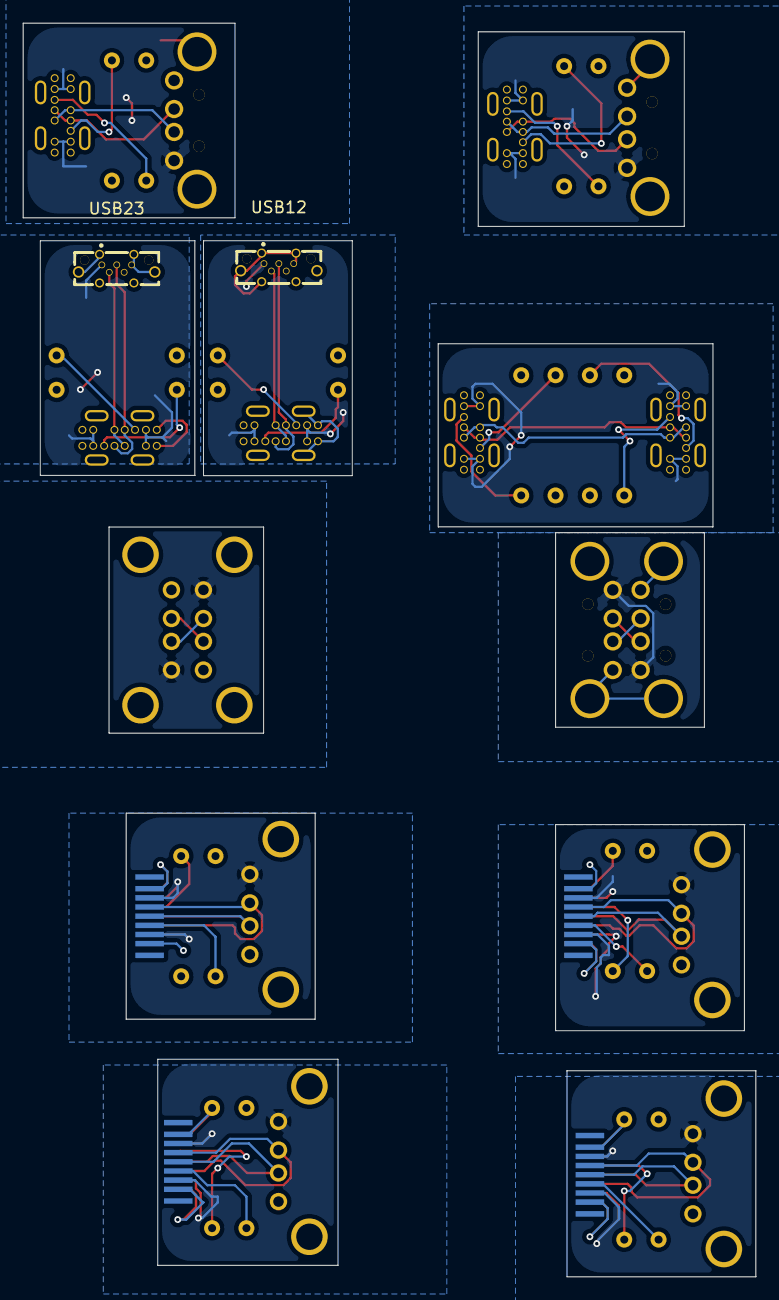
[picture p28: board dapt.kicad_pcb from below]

Board: 2 copper layers, 64.0 x 109.5 mm, 42 parts (2 on the bottom side), 64 nets.

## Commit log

2026-07-11 lwk the schematic and the routing
    [A_female_A_female.kicad_sch, A_female_C_male.kicad_sch, A_male_A_male.kicad_sch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]
2026-07-12 readme prelim
    [dapt.step]
